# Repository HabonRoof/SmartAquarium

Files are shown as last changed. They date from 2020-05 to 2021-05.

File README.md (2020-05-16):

### [- 硬體設備/Hardware](#硬體設備hardware) 

# IOT SmartAquarium

YouTube Link : https://www.youtube.com/watch?v=fPH_UBWnZz8

炎炎夏日，養魚種草的你是否擔心家裡魚缸的溫度會不會過高?
會不會擔心今天會不會太晚下班/下課回家，魚缸的燈忘記關，讓水缸爆藻?

別擔心，有了智慧魚缸控制器，以上困擾再也不會再出現!

使用聯發科 Linkit 7697 與聯發科的MCS雲端沙盒來實作物聯網魚缸，搭配繼電器以及DS18B20溫度感應器，讓你隨時隨地都可以監控魚缸的一切數值。

In a hot summer,are you worried about the temperature is too high for fish or shrimp?
Are you worried when you after work, the light of aquarium had been open too long so the alge growing very quickly?

Now, you have an IOT smart aquarium system, the troubles above will not happen anymore!
This project use Linkit7697 and MCS cloud sandbox service to build a smart IOT Aquarium system,
with relay and DS18B20 temperature sensor, you can monitor the value of your aquarium anytime anywhere!

# 硬體設備/Hardware
Components

1. 1x Linkit 7697

2. 1x 110v轉5V變壓器 或手機充電器 /ac 110v to dc 5v transformer or old phone charger

3. 4x 繼電器(耐壓110V,10A)  /relay 110V/10A

4. 6x 110V插座 /110V ac socket

5. 1x 開關盒/   switch box

6. 1.6 單心銅線/ 1.6mm core copper wire

# 軟體/Software
MCS雲端服務 / MCS introduction
https://mcs.mediatek.com/resources/latest/introduction

Arduino IDE 設定方法/ Arduino IDE Enviorment setup
https://docs.labs.mediatek.com/resource/linkit7697-arduino/en/environment-setup

# 成果/Result
外觀圖片
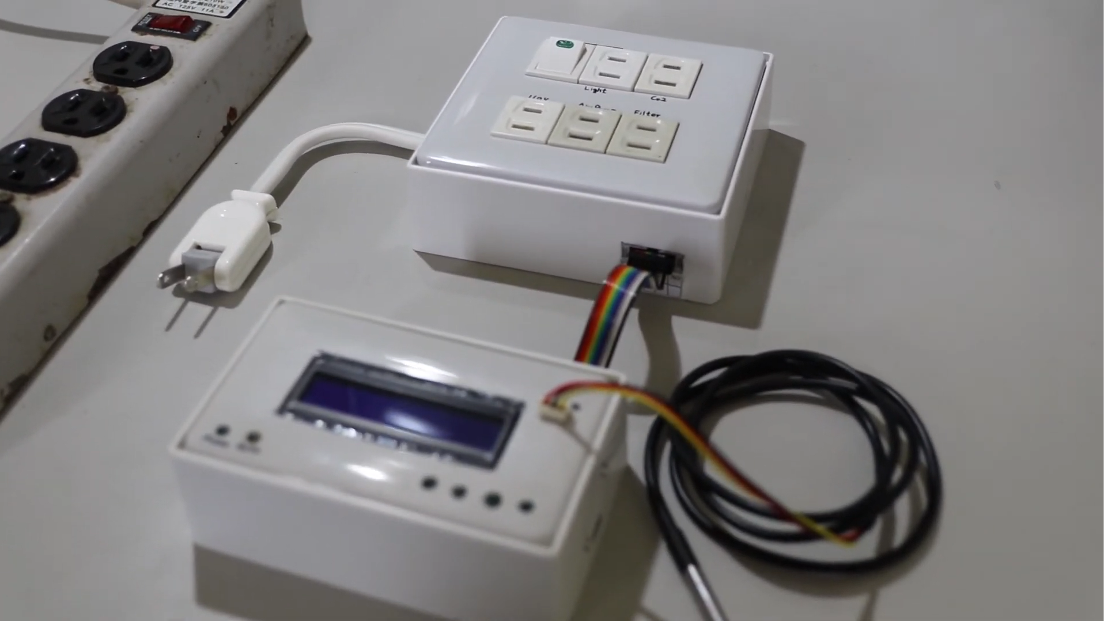
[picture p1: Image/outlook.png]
Outlook

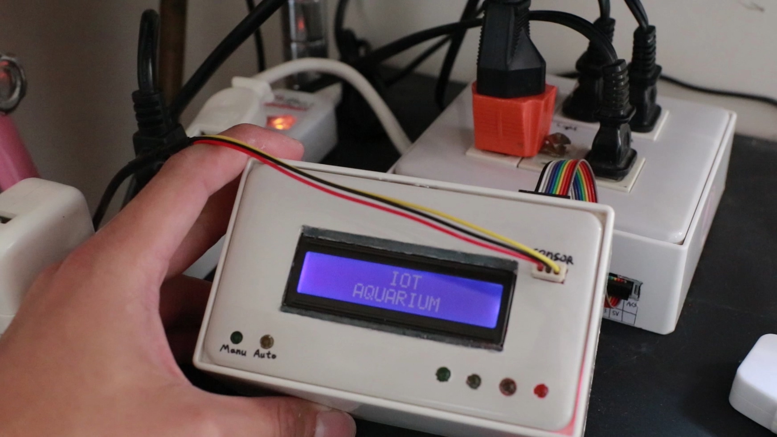
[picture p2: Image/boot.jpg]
Boost

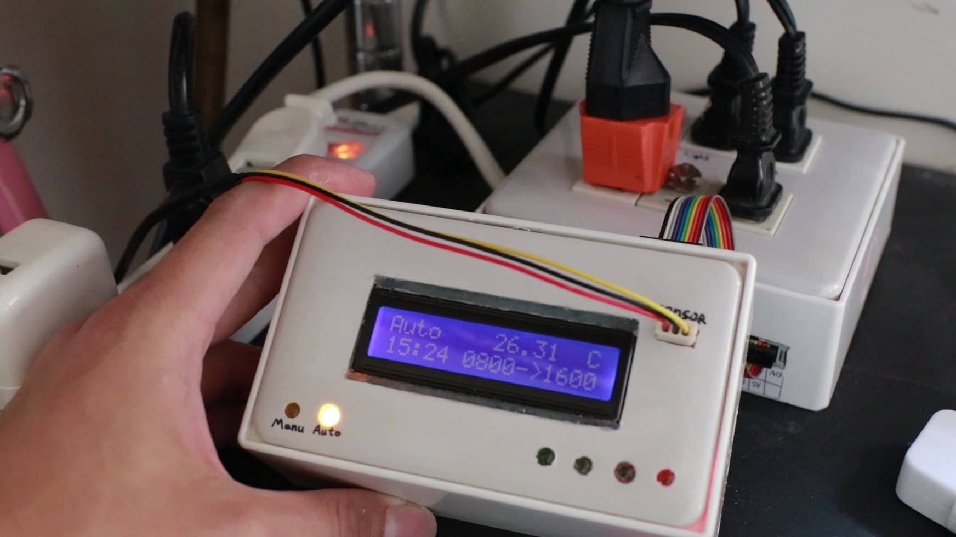
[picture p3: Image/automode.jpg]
Auto Mode

應用圖片
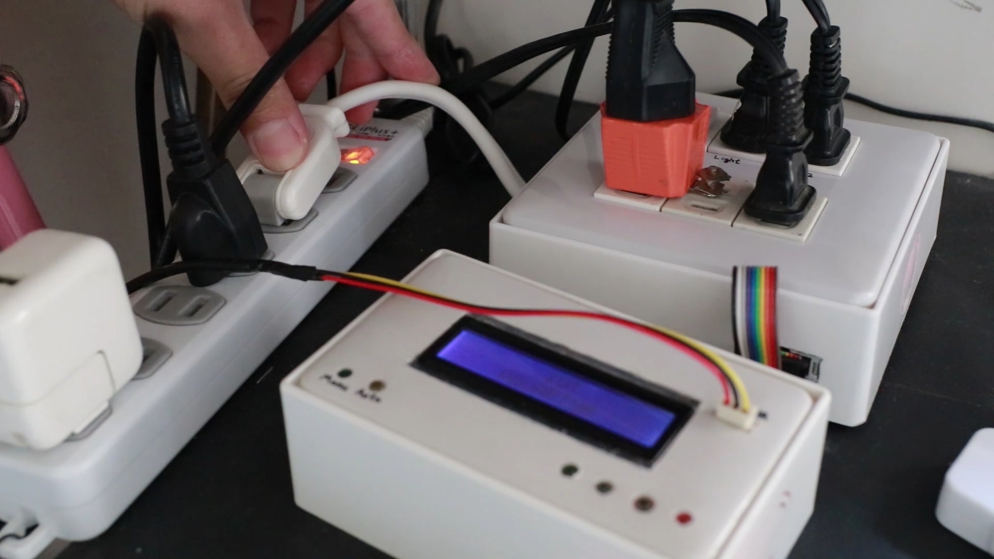
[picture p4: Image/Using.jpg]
Using


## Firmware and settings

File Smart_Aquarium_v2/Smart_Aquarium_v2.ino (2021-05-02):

/*
   Smart Aquarium V2.0
   2020/05/03
   https://www.instagram.com/habonroof/
   for more infomation, please visit my personal website:https://sites.google.com/ntut.org.tw/habonroofplayground-en/home
*/

// Include necessary library for MCS service
#include <LWiFi.h>
#include <WiFiClient.h>
#include "MCS.h"

// Include RTC library
#include <LRTC.h>

//Include WiFi UDP library to use UDP service to get NTP time from internet
#include <WiFiUDP.h>

//Include Dallas DS18B20 library
#include <OneWire.h>
#include <DallasTemperature.h>

//Include I2C LCD library
#include <LiquidCrystal_I2C.h>

//Assign temperature sensor data wire pin
#define one_wire_bus 4

//Assign AP ssid and password
#define mySSID "johnson"
#define myPSWD "j8701292929"

//Assign your test device id / key
//You can find it on your test device website
MCSLiteDevice mcs ("HJa45fhDd", "9bfe7255c4cdbf1c7c3db0e82702bf632b3b06faabee0a9443b853df2345a43f", "192.168.0.7", 3000);


//  MCS Channel Zone-------------------------------------------------------------------------------------------------------------------------------------------------------------------------
/*
  Assign your customize channel id
  How many channels your test device has,
  here should have the same amount channel id to transmit the data to MCS
  Be aware to the channel id type, may be Controller or Display
  And the name of channel id is use for downer code, not for MCS service website.
  For example:
  MCSControllerOnOff  Name_of_channel_id ("real_channel_id");
*/
MCSControllerOnOff  Light("Relay_1");
MCSControllerOnOff  Co2("Relay_2");
MCSControllerOnOff  AirPump("Relay_3");
MCSControllerOnOff  Filter("Relay_4");
MCSControllerOnOff  AutoMode("Auto_Mode");
MCSControllerInteger setHour("StartTime_hour");
MCSControllerInteger setMin("StartTime_min");
MCSControllerInteger Duration("Duration");
MCSDisplayOnOff     Light_state("RelayState_1");
MCSDisplayOnOff     Co2_state("RelayState_2");
MCSDisplayOnOff     AirPump_state("RelayState_3");
MCSDisplayOnOff     Filter_state("RelayState_4");
MCSDisplayFloat     Power("Eng");
MCSDisplayFloat     Temp("Temp");
MCSDisplayFloat     mcs_Current("Current");

//  NTP setup zone-------------------------------------------------------------------------------------------------------------------------------------------------------------------------
/*
  For more information about NTP, please vsit:https://en.wikipedia.org/wiki/Network_Time_Protocol
  This part of code is refer by Mediatek official example,
  You can find it at Arduino->File->Examples->Examples for Linkit7697->.LWiFi->WiFiUdpNtpClient
*/

unsigned int localPort = 2390;    //local port to listen for UDP packets, this port is located on Linkit7697

//Change this address depend on your location to get the more accurate time from NTP server
IPAddress timeServer(118, 163, 81, 61);         //Taiwan standard time NTP server IP address
const char *NTP_server = "time.stdtime.gov.tw"; //Use

const int TimeZone = 8;

const int NTP_PACKET_SIZE = 48;   // NTP time stamp is in the first 48 bytes of the message
byte packetBuffer[ NTP_PACKET_SIZE]; //buffer to hold incoming and outgoing packets

// Create a UDP object, a UDP instance to let us send and receive packets over UDP
WiFiUDP Udp;

// Setup onewire bus for DS18B20 ----------------------------------------------------------------------------------------------------------------------------------------------------------
OneWire onewire(one_wire_bus);        //create onewire bus object named onewire
DallasTemperature sensors(&onewire);  //pass onewire object into DallasTemperature object named sensors
float Temperature = 0;

// Setup I2C LCD address
LiquidCrystal_I2C lcd(0x27);          //set LiquidCrystal_I2C object named lcd, address is 0x27
// I2C of Linkit 7697: SDA -> P9  SCL -> P8
//  Define relay pin out ------------------------------------------------------------------------------------------------------------------------------------------------------------------
//Pin 8 is I2C SCL, Pin9 is I2C SDA, connect to I2C perpherial (LCD)
const byte Relay_1 = 10;          //Light relay
const byte Relay_2 = 11;          //Co2 relay
const byte Relay_3 = 12;          //AirPump relay
const byte Relay_4 = 13;          //Filter relay
const byte ACS712 = 14;           //ACS712 current sensor (30A)
const byte Automode_LED = 2;      //The reason not use pin 0 and 1 is because they are serial bus TX and RX
const byte Manualmode_LED = 3;


//  Define time parameter -----------------------------------------------------------------------------------------------------------------------------------------------------------------
//the light will be open if Nowtime in the range of duration
//For example:
//Start |Hour:Minute| -> |Duration(minute)| -> End |Hour:Minute|
//          OFF                 ON                      OFF
//Start |  08:00    | -> |    480min      | -> End |   16:00   |

byte StartHour = 0;     byte StartMin = 0;
byte EndHour = 0;       byte EndMin = 0;
byte NowHour = 0;       byte NowMin = 0;
byte NowSec = 0;        int OpeningTime = 0;
byte last_update_minute = 0;

// Define current sensor parameter --------------------------------------------------------------------------------------------------------------------------------------------------------
//Sensitivity means how much mV when 1A current flow through the sensor
//Reference to the official datasheet:https://www.sparkfun.com/datasheets/BreakoutBoards/0712.pdf
//5A measurement -> 185mV/A | 20A measurement -> 100mV/A | 30A measurement -> 66mV/A

const int sensitivity = 66;
float Current = 0;            //Current value
float Current_offset = 0.21;  //Constant error of current sensor, about 0.22A

//parameter to calculate power consumption-------------------------------------------------------------------------------------------------------------------------------------------------
const int Volt = 110;           //Voltage of your home's electronic power
float Energe = 0;               //Energe consumption

//-----------------------------------------------------------------------------------------------------------------------------------------------------------------------------------------

//Some convenient flags for serial print or LCD
bool LEDflag1 = false;
bool LEDflag2 = false;

//-----------------------------------------------------------------------------------------------------------------------------------------------------------------------------------------

void MCS_Init();
void RTC_Init();
void NTP_Init();
void LCD_Init();
void mcs_Addchannel();
void pin_setup();
void get_status_from_MCS();
void get_SetTime();
void timer_Mode();
void sendNTPpacket();
void check_MCS_connection();
void lcd_print_Automode_info();
void lcd_print_Manulemode_info();
void mcs_update_dataPoint();


//-----------------------------------------------------------------------------------------------------------------------------------------------------------------------------------------
//Add channels to MCS service, the name of channel id is above the code, not on the MCS website.
void mcs_Addchannel() {
  mcs.addChannel(Light);
  mcs.addChannel(Light_state);
  mcs.addChannel(Co2);
  mcs.addChannel(Co2_state);
  mcs.addChannel(AirPump);
  mcs.addChannel(AirPump_state);
  mcs.addChannel(Filter);
  mcs.addChannel(Filter_state);
  mcs.addChannel(AutoMode);
  mcs.addChannel(setHour);
  mcs.addChannel(setMin);
  mcs.addChannel(Duration);
  mcs.addChannel(Power);
  mcs.addChannel(Temp);
  mcs.addChannel(mcs_Current);
}

//Setup pin mode --------------------------------------------------------------------------------------------------------------------------------------------------------------------------
void pin_setup() {
  pinMode(Relay_1, OUTPUT);
  pinMode(Relay_2, OUTPUT);
  pinMode(Relay_3, OUTPUT);
  pinMode(Relay_4, OUTPUT);
  pinMode(ACS712, INPUT);
  pinMode(Automode_LED, OUTPUT);
  pinMode(Manualmode_LED, OUTPUT);
}

// Get relay state from MCS ---------------------------------------------------------------------------------------------------------------------------------------------------------------
void get_status_from_MCS() {
  //Get the switch state from MCS
  //and update the state to MCS display
  if (Light.updated()) {
    digitalWrite(Relay_1, Light.value() ? HIGH : LOW);
    Light_state.set(Light.value());
  }
  if (Co2.updated()) {
    digitalWrite(Relay_2, Co2.value() ? HIGH : LOW);
    Co2_state.set(Co2.value());
  }
  if (AirPump.updated()) {
    digitalWrite(Relay_3, AirPump.value() ? HIGH : LOW);
    AirPump_state.set(AirPump.value());
  }
  if (Filter.updated()) {
    digitalWrite(Relay_4, Filter.value() ? HIGH : LOW);
    Filter_state.set(Filter.value());
  }
}



// Get setting time from MCS ------------------------------------------------------------------------------------------------------------------------------------------------------------
void get_SetTime() {
  //Get set time from MCS, include the start time(hour), start time(minute), and opening time
  StartHour = setHour.value();
  StartMin = setMin.value();
  OpeningTime = Duration.value();
  //Calculate the end time
  EndHour = StartHour + (OpeningTime / 60);
  EndMin = StartMin + (OpeningTime % 60);
  //If end time(hour) is greater than 24, that means the end time is at next day, so we need reset the hour to prevent error
  if (EndHour >= 24)
    EndHour = EndHour - 24;
  //Same, if the end time(minute) is more than 60, means the end time need a carry to next hour.
  if (EndMin >= 60) {
    EndMin = EndMin - 60;
    EndHour += EndHour;
  }
}

// When Auto mode is on, goin to timer relay --------------------------------------------------------------------------------------------------------------------------------------------
void timer_Mode() {
  //Get now time from RTC
  LRTC.get();
  NowHour = LRTC.hour();
  NowMin = LRTC.minute();

  //Check current time is same as start time or not
  //if yes, then turn on the sepecific relay
  //if not, turn off the relay
  if (NowHour == StartHour && NowMin == StartMin) {           //Small bug : If now time is 12:00, but start time is 8:00 end time is 16:00 the relay should not be open
    digitalWrite(Relay_1, HIGH);  //turn on light relay
    digitalWrite(Relay_2, HIGH);  //turn on Co2 relay
  }
  if (NowHour == EndHour && NowMin == EndMin) {
    digitalWrite(Relay_1, LOW);   //turn off light relay
    digitalWrite(Relay_2, LOW);   //turn off Co2 relay
  }
}

// Get aquarium temperature via DS18B20 --------------------------------------------------------------------------------------------------------------------------------------------------
void get_Temperature() {
  sensors.requestTemperatures();                //Request all temperature sensor's value
  if (sensors.getTempCByIndex(0) < 0)           //Avoid error data (-127) caused by poor contact
    Temperature = Temperature;
  else
    Temperature = sensors.getTempCByIndex(0);   //get the temperature in Celsius at sensor index "0"
  // Temp.set(Temperature);                     //Update temperature to MCS (move to mcs_update_datapoint function)
  Serial.print("Temperature:");
  Serial.println(Temperature);
}

// Update data to MCS server per minutes to reduce usage of datapoint
void mcs_update_dataPoint() {
  LRTC.get();
  NowMin = LRTC.minute();
  if (NowMin - last_update_minute == 1) {             //To reduce MCS datapoint usage, update datapoint per minute
    Serial.println("Update to MCS per minute");
    mcs_Current.set(Current);
    Power.set(Energe);
    Temp.set(Temperature);
    
  }
  LRTC.get();
  last_update_minute = LRTC.minute();
}
// Check the device is online or not-----------------------------------------------------------------------------------------------------------------------------------------------------
void check_MCS_connection() {
  while (!mcs.connected())
    mcs.connect();
}
//----------------------------------------------------------------------------------------------------------------------------------------------------------------------------------------


void setup() {
  Serial.begin(115200);
  LCD_Init();
  pin_setup();
  MCS_Init();   //MCS_Init() include the wifi initial process, be the first process in setup
  NTP_Init();   //NTP_Init() update current time into RTC module, need to be execute before RTC_Init()
  RTC_Init();   //Set RTC time to reality real time

  //If the data is invalid, reget data from MCS
  while (!Light.valid() && !Co2.valid() && !AirPump.valid() && !Filter.valid() && !AutoMode.valid()) {
    Light.value();
    Co2.value();
    AirPump.value();
    Filter.value();
    AutoMode.value();
  }
  sensors.begin();        //Start DallasTemperature sensors
}


void loop() {
  //call process() to allow background processing, add timeout to avoid high cpu usage
  mcs.process(500);
  if (AutoMode.value()) {
    if (!LEDflag1) {
      Serial.println("Auto Mode");
      digitalWrite(Automode_LED, HIGH);
      digitalWrite(Manualmode_LED, LOW);
    }
    LEDflag1 = true;
    LEDflag2 = false;

    get_SetTime();              //Get the setting time from MCS via input box
    timer_Mode();               //Start timer mode, check now need to open or close the relay(s)
    lcd_print_Automode_info();
  }
  else {
    if (!LEDflag2) {
      Serial.println("Manual Mode");
      digitalWrite(Automode_LED, LOW);
      digitalWrite(Manualmode_LED, HIGH);
    }
    LEDflag2 = true;
    LEDflag1 = false;

    lcd_print_Manulemode_info();
    get_status_from_MCS();          //Control relays through MCS pannel
  }
  get_AC_Current();             //Refresh curremt meter value in main loop
  get_Temperature();            //Refresh temperature value in main loop
  mcs_update_dataPoint();       //Update data to MCS per minute
  check_MCS_connection();       //Check MCS connection in each loop
}

void lcd_print_Automode_info() {
  lcd.clear();
  lcd.print("Auto");
  lcd.setCursor(8, 0);
  lcd.print(Temperature);
  lcd.setCursor(14, 0);
  lcd.print(" C");
  
  if (NowHour < 10) {
    lcd.setCursor(0, 1);
    lcd.print("0");
    lcd.setCursor(1, 1);
    lcd.print(NowHour);
  }
  else {
    lcd.setCursor(0, 1);
    lcd.print(NowHour);
  }
  lcd.setCursor(2, 1);
  lcd.print(":");
  if (NowMin < 10) {
    lcd.setCursor(3, 1);
    lcd.print("0");
    lcd.setCursor(4, 1);
    lcd.print(NowMin);
  }
  else {
    lcd.setCursor(3, 1);
    lcd.print(NowMin);
  }

  if (StartHour < 10) {
    lcd.setCursor(6, 1);
    lcd.print("0");
    lcd.setCursor(7, 1);
    lcd.print(StartHour);
  }
  else {
    lcd.setCursor(6, 1);
    lcd.print(StartHour);
  }
  if (StartMin < 10) {
    lcd.setCursor(8, 1);
    lcd.print("0");
    lcd.setCursor(9, 1);
    lcd.print(StartMin);
  }
  else {
    lcd.setCursor(8, 1);
    lcd.print(StartMin);
  }
  lcd.setCursor(10, 1);
  lcd.print("->");
  if (EndHour < 10) {
    lcd.setCursor(12, 1);
    lcd.print("0");
    lcd.setCursor(13, 1);
    lcd.print(EndHour);
  }
  else {
    lcd.setCursor(12, 1);
    lcd.print(EndHour);
  }
  if (EndMin < 10) {
    lcd.setCursor(14, 1);
    lcd.print("0");
    lcd.setCursor(15, 1);
    lcd.print(EndMin);
  }
  else {
    lcd.setCursor(14, 1);
    lcd.print(EndMin);
  }
}

void lcd_print_Manulemode_info() {
  lcd.clear();
  lcd.print("Manu");
  lcd.setCursor(8, 0);
  lcd.print("Cur:");
  lcd.setCursor(12, 0);
  lcd.print(Current);
  if (NowHour < 10) {
    lcd.setCursor(0, 1);
    lcd.print("0");
    lcd.setCursor(1, 1);
    lcd.print(NowHour);
  }
  else {
    lcd.setCursor(0, 1);
    lcd.print(NowHour);
  }
  lcd.setCursor(2, 1);
  lcd.print(":");
  if (NowMin < 10) {
    lcd.setCursor(3, 1);
    lcd.print("0");
    lcd.setCursor(4, 1);
    lcd.print(NowMin);
  }
  else {
    lcd.setCursor(3, 1);
    lcd.print(NowMin);
  }
  lcd.setCursor(7,1);
  lcd.print("Eng:");
  lcd.setCursor(11,1);
  lcd.print(Energe);
}

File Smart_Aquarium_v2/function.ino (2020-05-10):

//Initialize MCS service and WiFi service -------------------------------------------------------------------------------------------------------------------------------------------------
void MCS_Init() {
  while (WL_CONNECTED != WiFi.status())         //Continuly conneting Wifi untill successful
    WiFi.begin(mySSID, myPSWD);                 //Connect WiFi
  Serial.println("WiFi connected!");
  mcs_Addchannel();                             //add channel to MCS
  while (!mcs.connected())
    mcs.connect();                              //Connect to MCS
}

// Initialize the RTC and set to real time ----------------------------------------------------------------------------------------------------------------------------------------------
void RTC_Init() {
  LRTC.begin();
  LRTC.set(2020, 5, 10, NowHour, NowMin, NowSec);  //Set the RTC time to 2020/05/05/ HH:MM:SS (NTP time) the date of RTC is not importand, so I ignore the process to update real date.
  LRTC.get();
  Serial.print("Nowtime ");
  Serial.print(LRTC.hour());
  Serial.print(":");
  Serial.print(LRTC.minute());
  Serial.print(":");
  Serial.println(LRTC.second());
}

// Initialize NTP server to get correct time from internet ------------------------------------------------------------------------------------------------------------------------------
void NTP_Init() {
  Udp.begin(localPort);
  // First,send an NTP packet to a time server,
  // and wait to see if a reply is available.
  sendNTPpacket(NTP_server);

  delay(5000);
  if (Udp.parsePacket()) {
    // We've received a packet, read the data into the buffer
    Udp.read(packetBuffer, NTP_PACKET_SIZE);

    //Second,the timestamp starts at byte 40 of the received packet and is four bytes,
    // or two words, long. we need to esxtract the two words:
    unsigned long highWord = word(packetBuffer[40], packetBuffer[41]);
    unsigned long lowWord = word(packetBuffer[42], packetBuffer[43]);

    // And combine the four bytes (two words) into a long integer
    unsigned long secsSince1900 = highWord << 16 | lowWord;

    // this is NTP time (seconds since Jan 1 1900):
    // But we need to convert NTP time into everyday time:
    const unsigned long seventyYears = 2208988800UL;              //Unix time starts on Jan 1 1970. In seconds, that's 2208988800 second

    unsigned long NowTime = secsSince1900 - seventyYears;         //get the current time from 1970/01/01 (second)

    //Updete time parameter into NTP time
    NowHour = (NowTime  % 86400L) / 3600 + TimeZone;              // Convert into hour (86400 equals secs per day)
    NowMin = (NowTime  % 3600) / 60;
    NowSec = (NowTime % 60);
  }
}

// send an NTP request to the time server at the given address----------------------------------------------------------------------------------------------------------------------------
unsigned long sendNTPpacket(const char* host) {
  
  // set all bytes in the buffer to 0
  memset(packetBuffer, 0, NTP_PACKET_SIZE);
  
  // Initialize values needed to form NTP request
  // (see NTP Wiki above for details on the packets)
  packetBuffer[0] = 0b11100011;   // LI, Version, Mode
  packetBuffer[1] = 0;            // Stratum, or type of clock
  packetBuffer[2] = 6;            // Polling Interval
  packetBuffer[3] = 0xEC;         // Peer Clock Precision
  // 8 bytes of zero for Root Delay & Root Dispersion
  packetBuffer[12]  = 49;
  packetBuffer[13]  = 0x4E;
  packetBuffer[14]  = 49;
  packetBuffer[15]  = 52;

  // all NTP fields have been given values, now
  // you can send a packet requesting a timestamp:
  Udp.beginPacket(host, 123); //NTP requests are to port 123

  Udp.write(packetBuffer, NTP_PACKET_SIZE);

  Udp.endPacket();

  return 0;
}

// Initialize the LCD screen -------------------------------------------------------------------------------------------------------------------------------------------------------------
void LCD_Init(){
  lcd.begin(16,2);
  lcd.setCursor(7,0);
  lcd.print("IOT");
  lcd.setCursor(4,1);
  lcd.print("AQUARIUM");
  delay(1000);
}

//Measure the current and send to MCS ---------------------------------------------------------------------------------------------------------------------------------------------------------
void get_AC_Current(){
  int analogVal = 0;              //Analog value read from the sensor pin
  int maxValue = 0;               //store max value, choose 0 to be the initial value
  int minValue = 4096;            //store min value, choose your microcontroller's "analog read max value" to be initial value (Arduino -> 1024)
  unsigned long CurrentTimer = millis();
  while((millis() - CurrentTimer) < 200){             //Sampling sensor value in 200mS period
      analogVal = analogRead(ACS712);
    if (analogVal > maxValue)                         //update max value
      maxValue = analogVal;
    if (analogVal < minValue)                         //update min value
      minValue = analogVal;
  }
  //Serial.print("Max val =");
  //Serial.print(maxValue);
  //Serial.print("/t");
  //Serial.print("Min val =");
  //Serial.println(minValue);
  float Vpp = (maxValue - minValue) * 5000 / 4096;    //Means peak-to-peak voltage is the max value - min value, and convert to the real voltage of ACS712 module, not ADC number.
                                                      //So the Vcc should be 5000mV instead of 2500mV.
  
  /* Limitations of Linkit7697 https://docs.labs.mediatek.com/resource/linkit7697-arduino/en/developer-guide/limitations-of-linkit-7697
   * Linkit 7697's ADC resolution is 4096 steps, and the voltage range is from 0 ~ 2.5V, here comes a problem:
   * Is the "Vpp" value calculate by the formula above correct or not?
   * The answer is NOT correct.
   * Because the neural point of module is 2.5V, is the maximum value of ADC input.
   * To completely fix this problem, you need to use two resisters (about 1k ohm) to make a voltage diviter, convert 5V to 2.5V proportionally, makes nural point to be 1.25V. 
   */
   
  Current = (Vpp / 2.0 * 0.707 / sensitivity) - Current_offset;           //Convert Vpp into Vrms, this value is the sensor's Vrms, and also represent current
  if(Current < 0)                                                         //Current is positive
    Current = 0;
  //Serial.print("Current =");
  //Serial.println(Current);
  //mcs_Current.set(Current);                                               //send current to MCS (move to mcs_update_datapoint function)
  Energe += (Volt * Current / 3600) / 1000;                               //Calculate power consumption and accumulate the energe. 
  //Power.set(Energe);                                                      //Send power consumption to MCS -> P = I*V (W), W = P * T (kW/H) (move to mcs_update_datapoint function)
}

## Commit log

2020-05-04 新增註解
2020-05-04 新增Arduino Code
2020-05-04 增加敘述
2020-05-05 新增MCS功能
2020-05-05 新增時間參數 Add time parameter
2020-05-05 刪除照片
2020-05-05 新增RTC校正功能 以及引入MCS定時功能
2020-05-06 Add ACS712 current sensor, but Serial port is broken
    [Smart_Aquarium_v2.ino]
2020-05-06 Fix Serial problem (change indicator pin) fix current be nagitive problem
    [Smart_Aquarium_v2.ino]
2020-05-06 Add DS18B20 temperature sensor
2020-05-07 Change local path of arduino file
2020-05-07 Add schematic files in /Schematic, and modified some functions in function.ino
    [PCB1.PcbDoc, Sheet1.SchDoc, SmartAquarium.PrjPcb]
2020-05-07 Add manual mode LCD display contant, rename the printflag into LEDflag
2020-05-07 update schmatic
    [Sheet1.SchDoc]
2020-05-08 Update schematic
2020-05-10 fix some small bugs
    [Smart_Aquarium_v2.ino, function.ino]
2021-05-02 Modify from MCS into MCS Lite
    [Sheet1.SchDoc, SmartAquarium.PrjPcb]
